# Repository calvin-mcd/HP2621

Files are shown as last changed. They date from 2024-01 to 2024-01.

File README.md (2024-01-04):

# HP2621

A pcb based on the HP2621 vintage home computer, supporting both MX and Alps switches and an extensive bottomrow.

Two case designs are being worked on by @obobobobo and fivedee.

## Layout

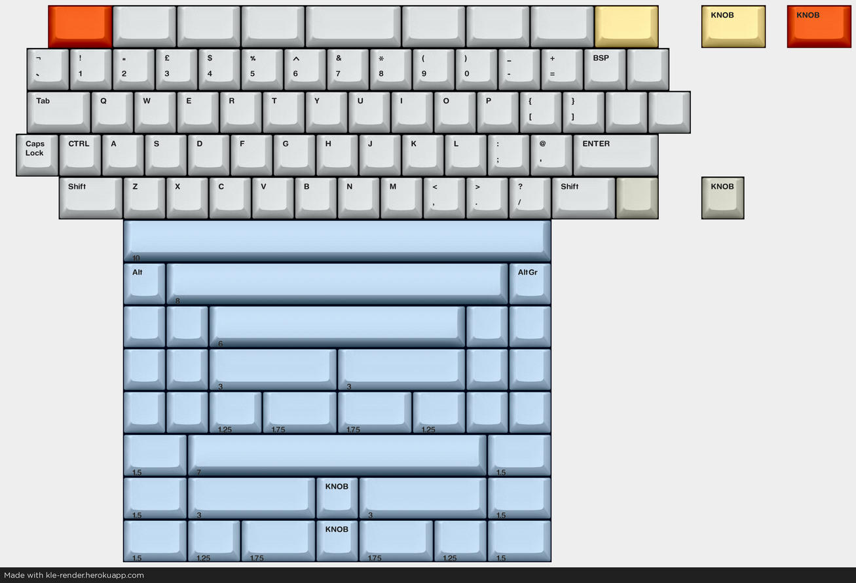
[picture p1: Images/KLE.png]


[Link](http://www.keyboard-layout-editor.com/#/gists/fb3fb2c8d70fd99746aac4b5d0be48f5)

## Pictures

The OG keyboard/computer inspiration
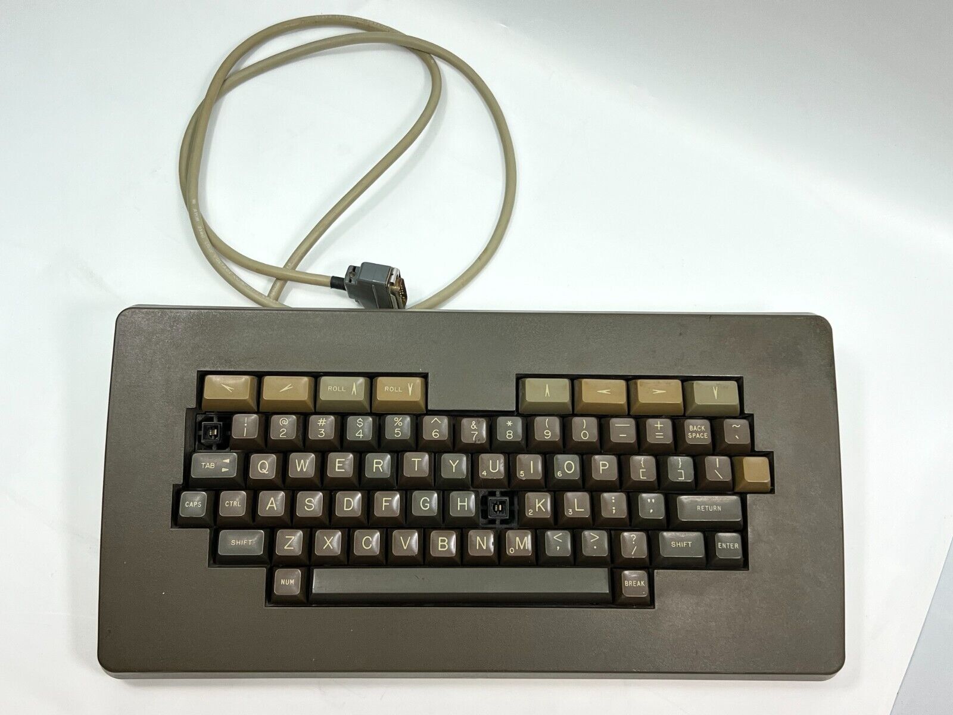
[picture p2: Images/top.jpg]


## Todo

- [ ] order & test pcb
- [ ] create firmware
- [ ] create & test cases

## Disclaimer

Please note that this project is a work in progress with no guarantees of a working outcome. No-one involved in this project is responsible for any usage issues that may arise. However, feel free to edit, modify and otherwise utilise these files.

## License

This project is released under the GPL v3 License. Please refer to the LICENCE file.

## Credits

Any questions, contact Calvin0563 on Discord.

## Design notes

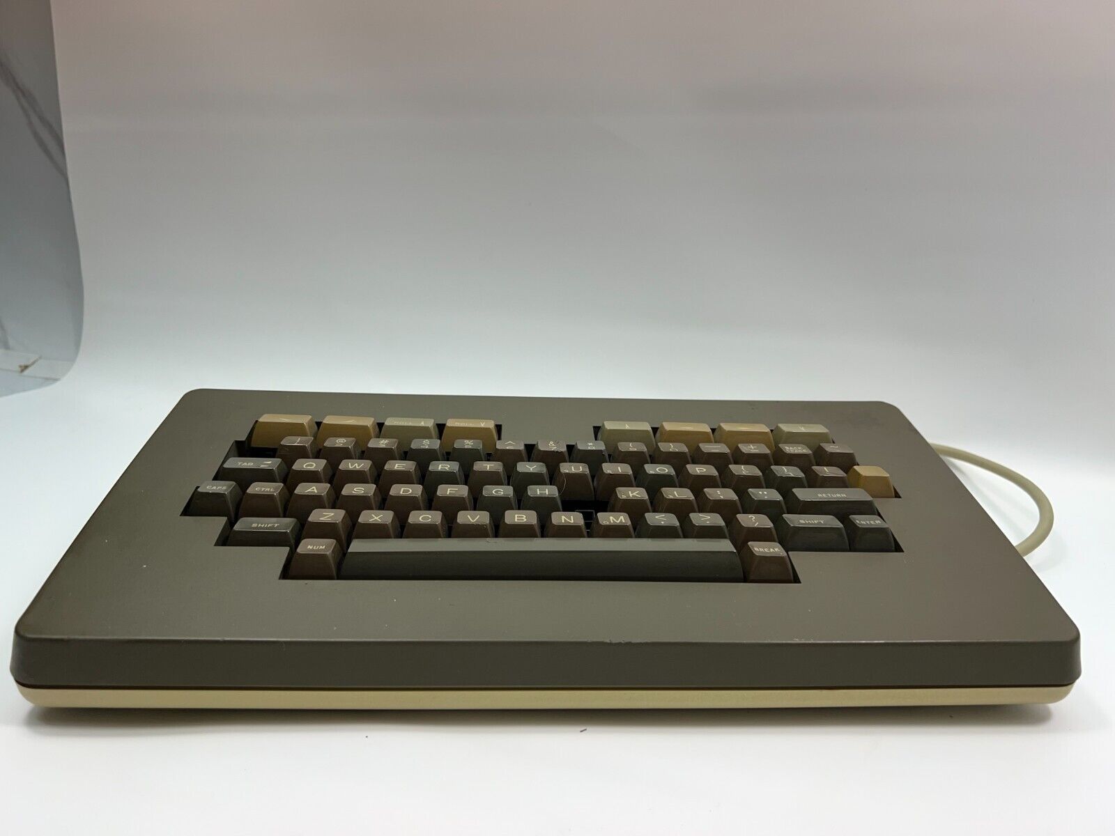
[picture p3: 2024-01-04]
Images/front.jpg

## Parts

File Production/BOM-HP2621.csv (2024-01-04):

Comment | Designator | Footprint | LCSC
SKQGABE010 | SW5 | SW_SPST_SKQG_WithStem | C115351
10k | R1 | R_0402_1005Metric | C25744
100nF | C1,C2,C3,C4,C5,C7 | C_0402_1005Metric | C307331
1uF | C8,C9 | C_0402_1005Metric | C52923
XC6206PxxxMR-Regulator_Linear | U1 | SOT-23 | C5446
Pico EZmate | J2 | Molex_Pico-EZmate_78171-0004_1x04-1MP_P1.20mm_Vertical | C588524
D_Small | D1,D10,D11,D12,D13,D14,D15,D16,D17,D18,D19,D2,D20,D21,D22,D23,D24,D25,D26,D27,D28,D29,D3,D30,D31,D32,D33,D34,D35,D36,D37,D38,D39,D4,D40,D41,D42,D43,D44,D45,D46,D47,D48,D49,D5,D50,D51,D52,D53,D54,D55,D56,D57,D58,D59,D6,D60,D61,D62,D63,D64,D65,D66,D67,D68,D69,D7,D70,D71,D72,D73,D74,D8,D9 | D_SOD-123F | C81598
STM32F072CBT6 | U2 | LQFP-48_7x7mm_P0.5mm | C81720
10uF | C6 | C_0603_1608Metric | C96446

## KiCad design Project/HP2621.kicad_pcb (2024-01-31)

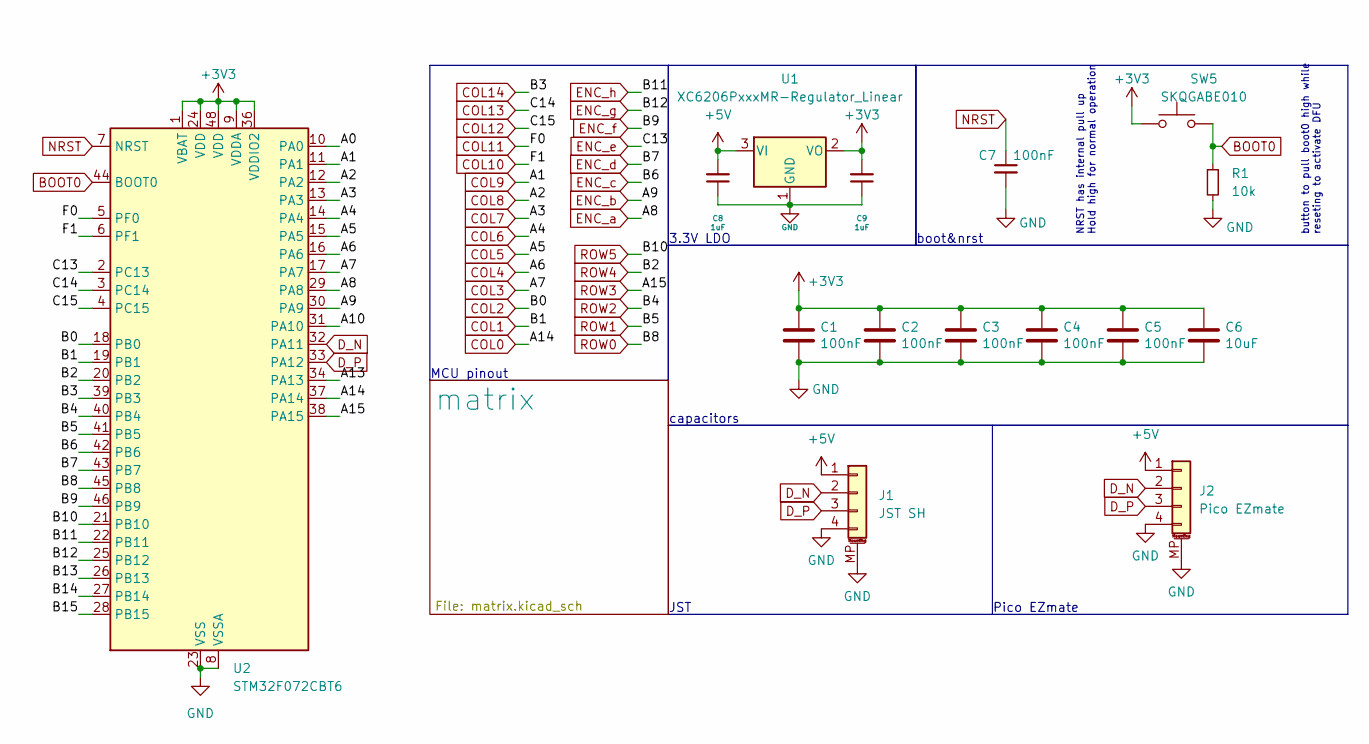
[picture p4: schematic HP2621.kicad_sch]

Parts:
C1, C2, C3, C4, C5, C7: 100nF; C_0402_1005Metric; LCSC C307331
C6: 10uF; C_0603_1608Metric
C8, C9: 1uF; C_0402_1005Metric; LCSC C52923
J1: JST SH; JST_SH_SM04B-SRSS-TB_1x04-1MP_P1.00mm_Horizontal
J2: Pico EZmate; Molex_Pico-EZmate_78171-0004_1x04-1MP_P1.20mm_Vertical
R1: 10k; R_0402_1005Metric
SW5: SKQGABE010; SW_SPST_SKQG_WithStem; LCSC C115351
U1: XC6206PxxxMR-Regulator_Linear; SOT-23; LCSC C5446
U2: STM32F072CBT6; LQFP-48_7x7mm_P0.5mm; JlcRotOffset 90

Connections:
+3V3: C1.1, C2.1, C3.1, C4.1, C5.1, C6.1, C9.2, SW5.1, U1.2 (VO), U2.1 (VBAT), U2.9 (VDDA), U2.24 (VDD), U2.36 (VDDIO2), U2.48 (VDD)
+5V: C8.2, J1.1, J2.1, U1.3 (VI)
/A0: U2.10 (PA0)
/A10: U2.31 (PA10)
/A13: U2.34 (PA13)
/B13: U2.26 (PB13)
/B14: U2.27 (PB14)
/B15: U2.28 (PB15)
BOOT0: R1.1, SW5.2, U2.44 (BOOT0)
COL0: U2.37 (PA14); also elsewhere on the board
COL1: U2.19 (PB1); also elsewhere on the board
COL2: U2.18 (PB0); also elsewhere on the board
COL3: U2.17 (PA7); also elsewhere on the board
COL4: U2.16 (PA6); also elsewhere on the board
COL5: U2.15 (PA5); also elsewhere on the board
COL6: U2.14 (PA4); also elsewhere on the board
COL7: U2.13 (PA3); also elsewhere on the board
COL8: U2.12 (PA2); also elsewhere on the board
COL9: U2.11 (PA1); also elsewhere on the board
COL10: U2.6 (PF1); also elsewhere on the board
COL11: U2.5 (PF0); also elsewhere on the board
COL12: U2.4 (PC15); also elsewhere on the board
COL13: U2.3 (PC14); also elsewhere on the board
COL14: U2.39 (PB3); also elsewhere on the board
D_N: J1.2, J2.2, U2.32 (PA11)
D_P: J1.3, J2.3, U2.33 (PA12)
ENC_a: U2.29 (PA8); also elsewhere on the board
ENC_b: U2.30 (PA9); also elsewhere on the board
ENC_c: U2.42 (PB6); also elsewhere on the board
ENC_d: U2.43 (PB7); also elsewhere on the board
ENC_e: U2.2 (PC13); also elsewhere on the board
ENC_f: U2.46 (PB9); also elsewhere on the board
ENC_g: U2.25 (PB12); also elsewhere on the board
ENC_h: U2.22 (PB11); also elsewhere on the board
GND: C1.2, C2.2, C3.2, C4.2, C5.2, C6.2, C7.2, C8.1, C9.1, J1.4, J1.MP (MountPin), J2.4, J2.MP (MountPin), R1.2, U1.1 (GND), U2.8 (VSSA), U2.23 (VSS), U2.35 (VSS), U2.47 (VSS); also elsewhere on the board
NRST: C7.1, U2.7 (NRST)
ROW0: U2.45 (PB8); also elsewhere on the board
ROW1: U2.41 (PB5); also elsewhere on the board
ROW2: U2.40 (PB4); also elsewhere on the board
ROW3: U2.38 (PA15); also elsewhere on the board
ROW4: U2.20 (PB2); also elsewhere on the board
ROW5: U2.21 (PB10); also elsewhere on the board

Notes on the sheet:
3.3V LDO
capacitors
NRST has internal pull up Hold high for normal operation
boot&nrst
MCU pinout
Pico EZmate
JST
button to pull boot0 high while reseting to activate DFU

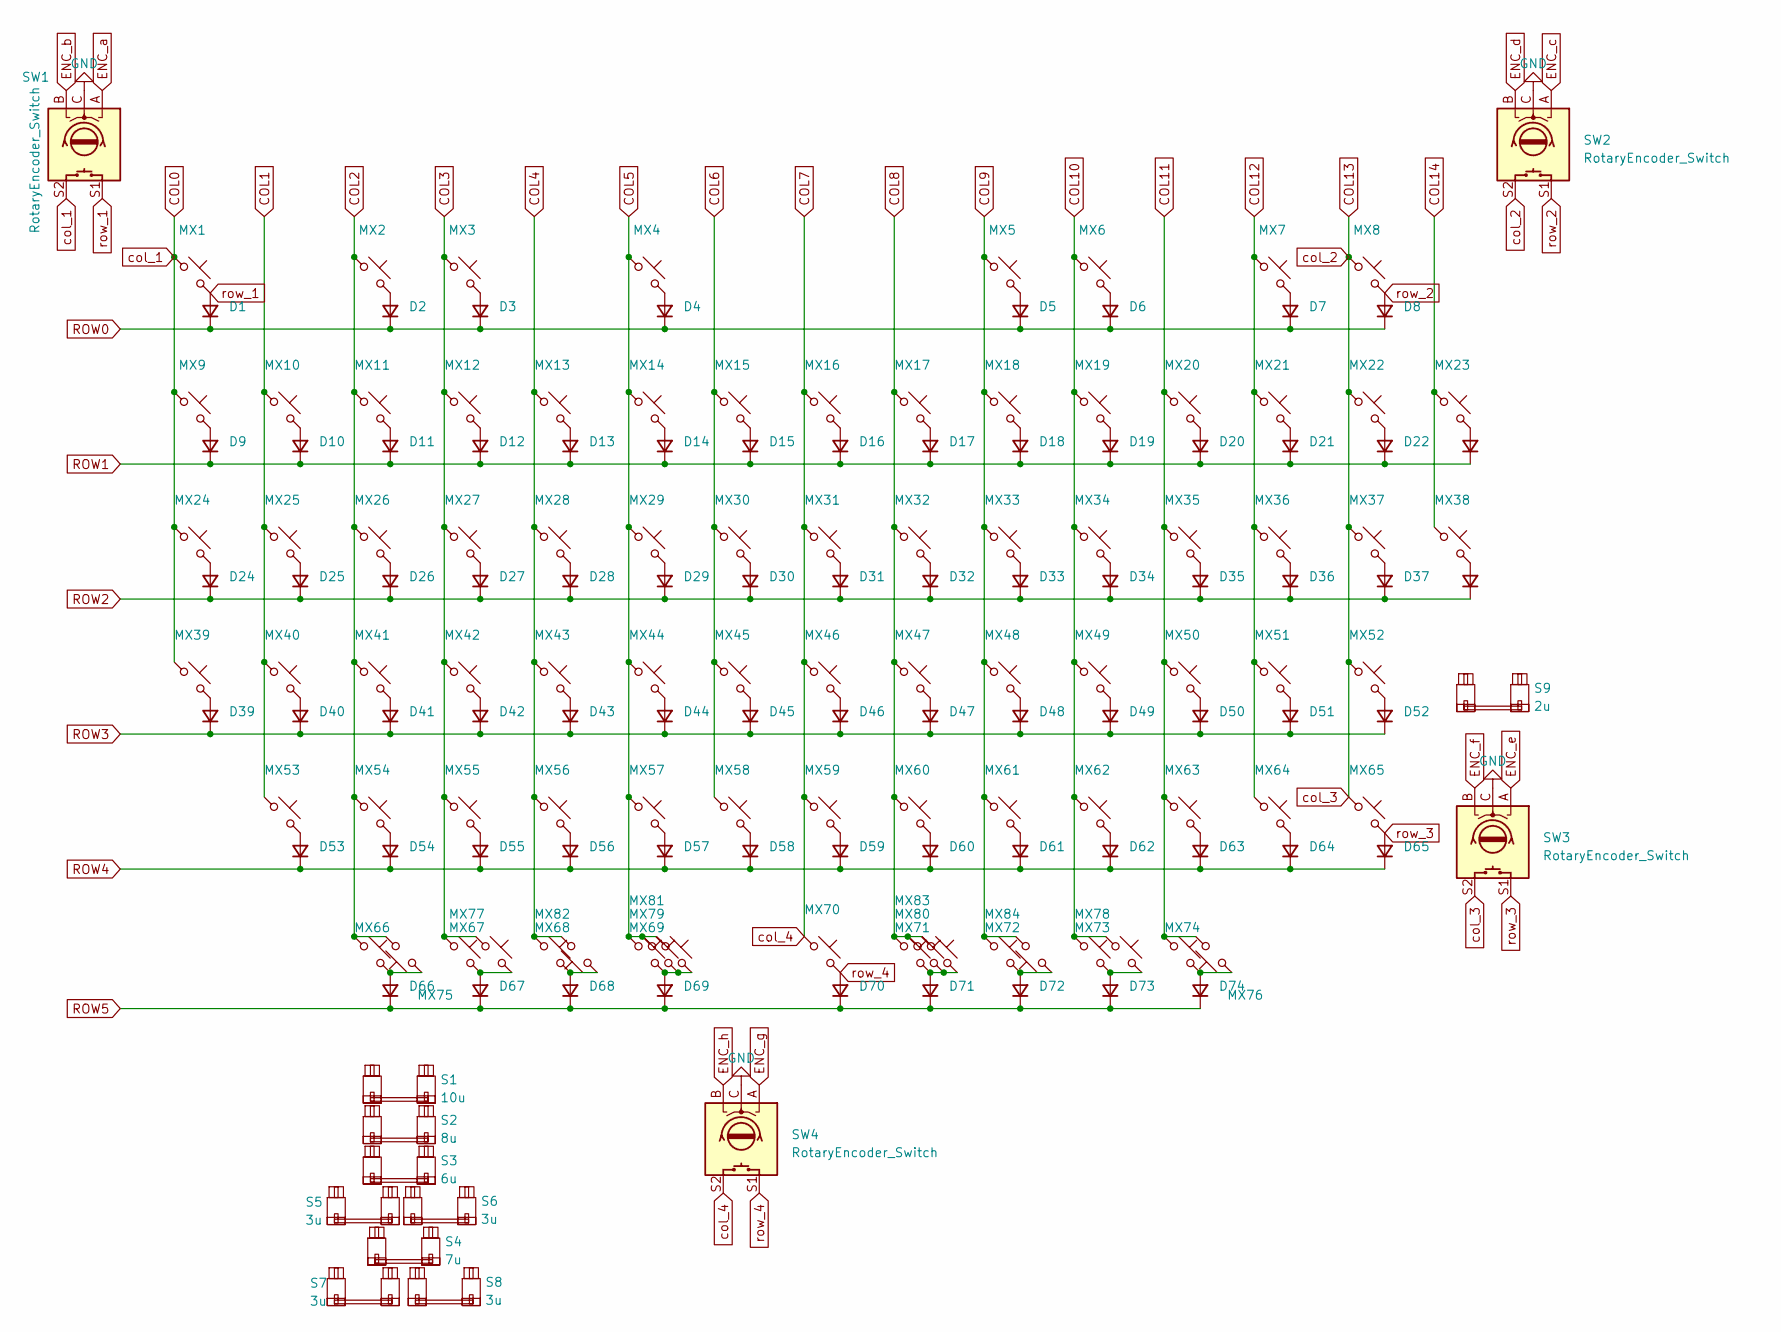
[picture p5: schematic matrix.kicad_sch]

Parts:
D1, D2, D3, D4, D5, D6, D7, D8, D9, D10, D11, D12, D13, D14, D15, D16, D17, D18, D19, D20, D21, D22, D23, D24, D25, D26, D27, D28, D29, D30, D31, D32, D33, D34, D35, D36, D37, D38, D39, D40, D41, D42, D43, D44, D45, D46, D47, D48, D49, D50, D51, D52, D53, D54, D55, D56, D57, D58, D59, D60, D61, D62, D63, D64, D65, D66, D67, D68, D69, D70, D71, D72, D73, D74: D_Small; D_SOD-123F
MX1, MX2, MX3, MX4, MX5, MX6, MX7, MX8, MX24, MX53, MX64, MX75, MX76: MX_SW_solder; SW_Alps_MX_1.5u
MX9, MX10, MX11, MX12, MX13, MX14, MX15, MX16, MX17, MX18, MX19, MX20, MX21, MX22, MX23, MX25, MX26, MX27, MX28, MX29, MX30, MX31, MX32, MX33, MX34, MX35, MX36, MX37, MX38, MX39, MX40, MX41, MX42, MX43, MX44, MX45, MX46, MX47, MX48, MX49, MX50, MX51, MX52, MX54, MX55, MX56, MX57, MX58, MX59, MX60, MX61, MX62, MX63, MX65, MX66, MX67, MX70, MX73, MX74, MX81, MX82, MX83, MX84: MX_SW_solder; SW_Alps_MX_1u
MX68, MX72, MX77, MX78: MX_SW_solder; SW_Alps_MX_1.25u
MX69, MX71, MX79, MX80: MX_SW_solder; SW_Alps_MX_1.75u
S1: 10u; STAB_MX_10u
S2: 8u; STAB_MX_8u
S3: 6u; STAB_MX_6u
S4: 7u; STAB_MX_7u
S5, S6, S7, S8: 3u; STAB_MX_3u
S9: 2u; STAB_MX_2u
SW1, SW2, SW3, SW4: RotaryEncoder_Switch; ROT_Alps_EC11E-Switch

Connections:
COL0: MX1.1, MX9.1, MX24.1, MX39.1, SW1.S2; also elsewhere on the board
COL1: MX10.1, MX25.1, MX40.1, MX53.1; also elsewhere on the board
COL2: MX2.1, MX11.1, MX26.1, MX41.1, MX54.1, MX66.1, MX75.2; also elsewhere on the board
COL3: MX3.1, MX12.1, MX27.1, MX42.1, MX55.1, MX67.1, MX77.1; also elsewhere on the board
COL4: MX13.1, MX28.1, MX43.1, MX56.1, MX68.1, MX82.2; also elsewhere on the board
COL5: MX4.1, MX14.1, MX29.1, MX44.1, MX57.1, MX69.1, MX79.1, MX81.1; also elsewhere on the board
COL6: MX15.1, MX30.1, MX45.1, MX58.1; also elsewhere on the board
COL7: MX16.1, MX31.1, MX46.1, MX59.1, MX70.1, SW4.S2; also elsewhere on the board
COL8: MX17.1, MX32.1, MX47.1, MX60.1, MX71.1, MX80.1, MX83.1; also elsewhere on the board
COL9: MX5.1, MX18.1, MX33.1, MX48.1, MX61.1, MX72.1, MX84.2; also elsewhere on the board
COL10: MX6.1, MX19.1, MX34.1, MX49.1, MX62.1, MX73.1, MX78.1; also elsewhere on the board
COL11: MX20.1, MX35.1, MX50.1, MX63.1, MX74.1, MX76.2; also elsewhere on the board
COL12: MX7.1, MX21.1, MX36.1, MX51.1, MX64.1; also elsewhere on the board
COL13: MX8.1, MX22.1, MX37.1, MX52.1, MX65.1, SW2.S2, SW3.S2; also elsewhere on the board
COL14: MX23.1, MX38.1; also elsewhere on the board
ENC_a: SW1.A; also elsewhere on the board
ENC_b: SW1.B; also elsewhere on the board
ENC_c: SW2.A; also elsewhere on the board
ENC_d: SW2.B; also elsewhere on the board
ENC_e: SW3.A; also elsewhere on the board
ENC_f: SW3.B; also elsewhere on the board
ENC_g: SW4.A; also elsewhere on the board
ENC_h: SW4.B; also elsewhere on the board
GND: SW1.C, SW2.C, SW3.C, SW4.C; also elsewhere on the board
unnamed: D2.2 (A), MX2.2
unnamed: D3.2 (A), MX3.2
unnamed: D4.2 (A), MX4.2
unnamed: D5.2 (A), MX5.2
unnamed: D6.2 (A), MX6.2
unnamed: D7.2 (A), MX7.2
unnamed: D9.2 (A), MX9.2
unnamed: D10.2 (A), MX10.2
unnamed: D11.2 (A), MX11.2
unnamed: D12.2 (A), MX12.2
unnamed: D13.2 (A), MX13.2
unnamed: D14.2 (A), MX14.2
unnamed: D15.2 (A), MX15.2
unnamed: D16.2 (A), MX16.2
unnamed: D17.2 (A), MX17.2
unnamed: D18.2 (A), MX18.2
unnamed: D19.2 (A), MX19.2
unnamed: D20.2 (A), MX20.2
unnamed: D21.2 (A), MX21.2
unnamed: D22.2 (A), MX22.2
unnamed: D23.2 (A), MX23.2
unnamed: D24.2 (A), MX24.2
unnamed: D25.2 (A), MX25.2
unnamed: D26.2 (A), MX26.2
unnamed: D27.2 (A), MX27.2
unnamed: D28.2 (A), MX28.2
unnamed: D29.2 (A), MX29.2
unnamed: D30.2 (A), MX30.2
unnamed: D31.2 (A), MX31.2
unnamed: D32.2 (A), MX32.2
unnamed: D33.2 (A), MX33.2
unnamed: D34.2 (A), MX34.2
unnamed: D35.2 (A), MX35.2
unnamed: D36.2 (A), MX36.2
unnamed: D37.2 (A), MX37.2
unnamed: D38.2 (A), MX38.2
unnamed: D39.2 (A), MX39.2
unnamed: D40.2 (A), MX40.2
unnamed: D41.2 (A), MX41.2
unnamed: D42.2 (A), MX42.2
unnamed: D43.2 (A), MX43.2
unnamed: D44.2 (A), MX44.2
unnamed: D45.2 (A), MX45.2
unnamed: D46.2 (A), MX46.2
unnamed: D47.2 (A), MX47.2
unnamed: D48.2 (A), MX48.2
unnamed: D49.2 (A), MX49.2
unnamed: D50.2 (A), MX50.2
unnamed: D51.2 (A), MX51.2
unnamed: D52.2 (A), MX52.2
unnamed: D53.2 (A), MX53.2
unnamed: D54.2 (A), MX54.2
unnamed: D55.2 (A), MX55.2
unnamed: D56.2 (A), MX56.2
unnamed: D57.2 (A), MX57.2
unnamed: D58.2 (A), MX58.2
unnamed: D59.2 (A), MX59.2
unnamed: D60.2 (A), MX60.2
unnamed: D61.2 (A), MX61.2
unnamed: D62.2 (A), MX62.2
unnamed: D63.2 (A), MX63.2
unnamed: D64.2 (A), MX64.2
unnamed: D66.2 (A), MX66.2, MX75.1
unnamed: D67.2 (A), MX67.2, MX77.2
unnamed: D68.2 (A), MX68.2, MX82.1
unnamed: D69.2 (A), MX69.2, MX79.2, MX81.2
unnamed: D71.2 (A), MX71.2, MX80.2, MX83.2
unnamed: D72.2 (A), MX72.2, MX84.1
unnamed: D73.2 (A), MX73.2, MX78.2
unnamed: D74.2 (A), MX74.2, MX76.1
ROW0: D1.1 (K), D2.1 (K), D3.1 (K), D4.1 (K), D5.1 (K), D6.1 (K), D7.1 (K), D8.1 (K); also elsewhere on the board
ROW1: D9.1 (K), D10.1 (K), D11.1 (K), D12.1 (K), D13.1 (K), D14.1 (K), D15.1 (K), D16.1 (K), D17.1 (K), D18.1 (K), D19.1 (K), D20.1 (K), D21.1 (K), D22.1 (K), D23.1 (K); also elsewhere on the board
ROW2: D24.1 (K), D25.1 (K), D26.1 (K), D27.1 (K), D28.1 (K), D29.1 (K), D30.1 (K), D31.1 (K), D32.1 (K), D33.1 (K), D34.1 (K), D35.1 (K), D36.1 (K), D37.1 (K), D38.1 (K); also elsewhere on the board
ROW3: D39.1 (K), D40.1 (K), D41.1 (K), D42.1 (K), D43.1 (K), D44.1 (K), D45.1 (K), D46.1 (K), D47.1 (K), D48.1 (K), D49.1 (K), D50.1 (K), D51.1 (K), D52.1 (K); also elsewhere on the board
ROW4: D53.1 (K), D54.1 (K), D55.1 (K), D56.1 (K), D57.1 (K), D58.1 (K), D59.1 (K), D60.1 (K), D61.1 (K), D62.1 (K), D63.1 (K), D64.1 (K), D65.1 (K); also elsewhere on the board
ROW5: D66.1 (K), D67.1 (K), D68.1 (K), D69.1 (K), D70.1 (K), D71.1 (K), D72.1 (K), D73.1 (K), D74.1 (K); also elsewhere on the board
row_1: D1.2 (A), MX1.2, SW1.S1
row_2: D8.2 (A), MX8.2, SW2.S1
row_3: D65.2 (A), MX65.2, SW3.S1
row_4: D70.2 (A), MX70.2, SW4.S1

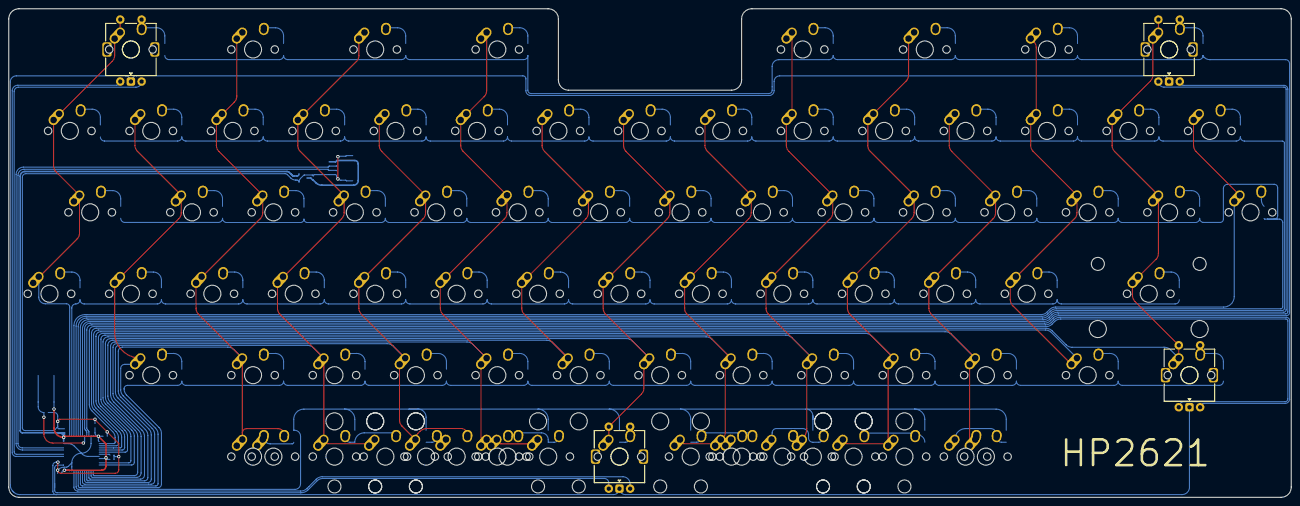
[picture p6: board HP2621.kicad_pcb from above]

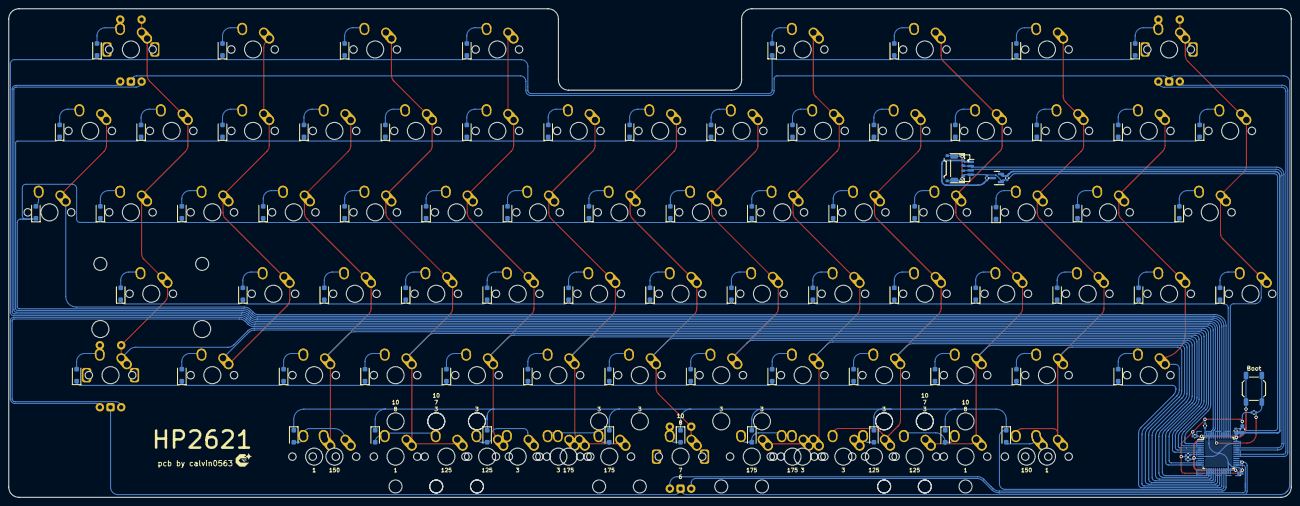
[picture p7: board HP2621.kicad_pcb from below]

Board: 2 copper layers, 300.0 x 114.3 mm, 184 parts (89 on the bottom side), 110 nets.

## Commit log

2024-01-04 silkscreen correction, fresh gerbers
    [BOM-HP2621.csv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]
2024-01-31 fresh gerbers
    [HP2621-B_Cu.gbr, HP2621-B_Mask.gbr, HP2621-B_Paste.gbr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]
